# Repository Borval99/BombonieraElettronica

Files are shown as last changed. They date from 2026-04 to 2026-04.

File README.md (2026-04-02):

# Bomboniera Elettronica

## Descrizione

BombonieraElettronica è una bomboniera realizzata in occasione della tesi di Laurea Magistrale in Ingegneria Elettronica.

Il dispositivo è basato su un circuito stampato (PCB) che integra una semplice logica elettronica per la generazione di un effetto luminoso.

---

## Funzionamento

La bomboniera è dotata di un **interruttore touch**, integrato nel cappello di laurea, che consente di attivare e disattivare il circuito.

Il sistema di illuminazione è realizzato tramite un **multivibratore astabile a BJT**, che genera un segnale oscillante utilizzato per pilotare 5 Led gialli.

Il risultato è un gioco di luci intermittente.

L’alimentazione è fornita da una **batteria CR2032**, rendendo il dispositivo compatto e autonomo. La durata da spento è stimata di circa 2 Anni.

---

## Immagini

<div>
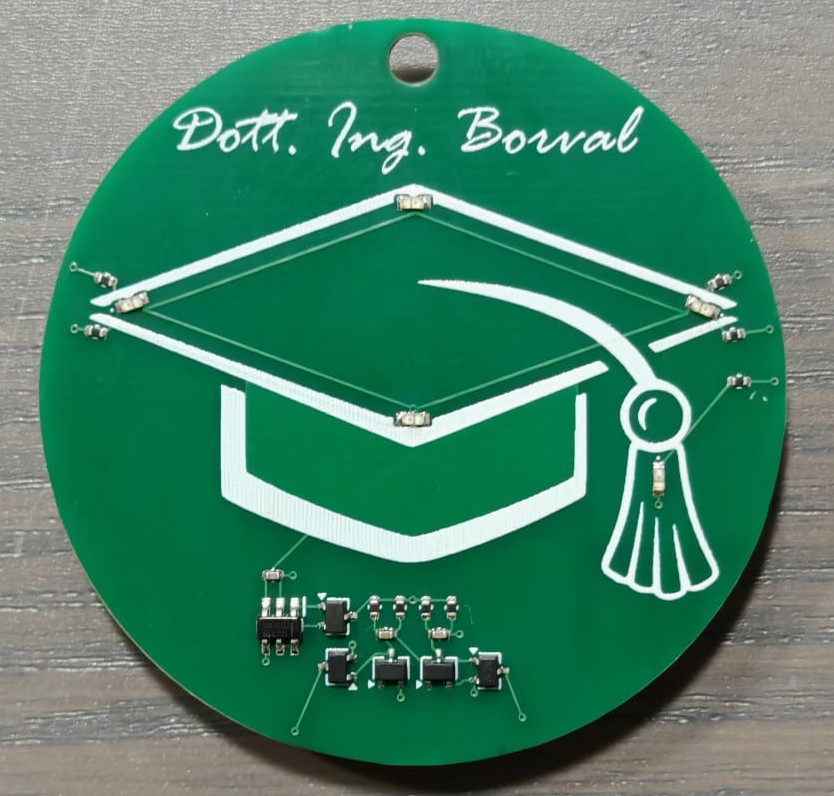
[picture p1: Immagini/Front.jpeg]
  
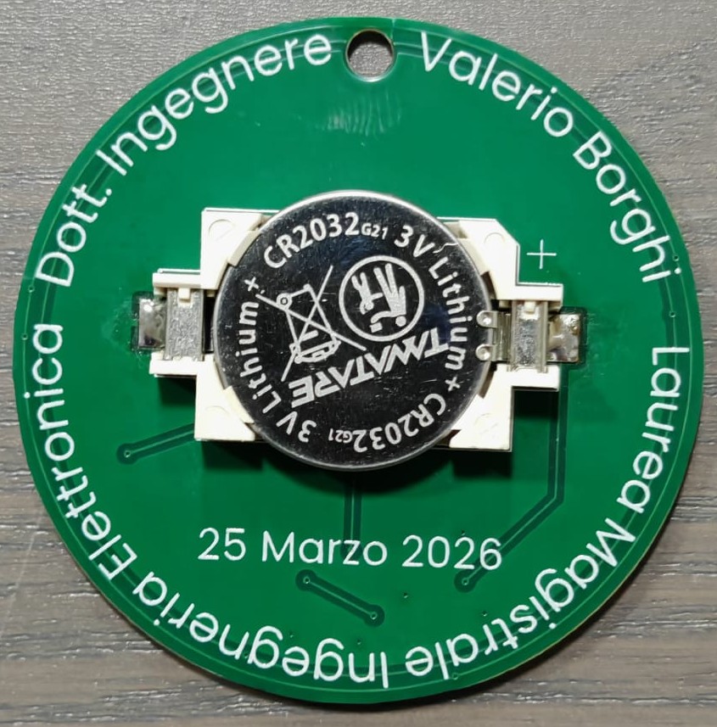
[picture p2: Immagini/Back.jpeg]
  
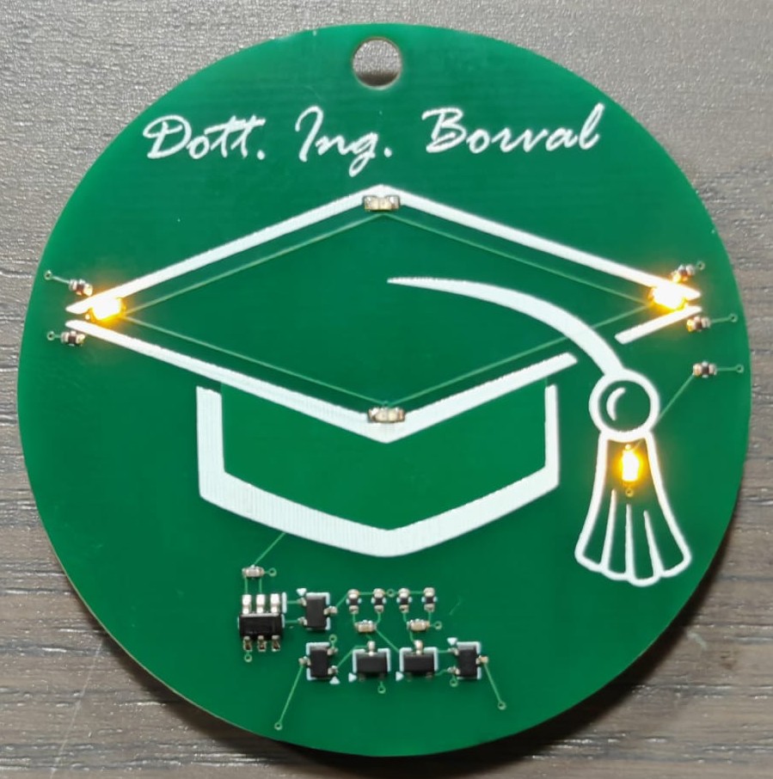
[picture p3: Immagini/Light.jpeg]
  
</div>

---

## Struttura della repository

### /Bomboniera_Tesi

Contiene il progetto elettronico completo realizzato in KiCad:

* schema elettrico
* layout del PCB

---

### /LTspice

Contiene le simulazioni dei circuiti sviluppati:

* modelli del multivibratore astabile
* analisi del comportamento del circuito

---

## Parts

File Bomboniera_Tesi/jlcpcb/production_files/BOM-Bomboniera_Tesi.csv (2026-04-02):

Comment | Designator | Footprint | LCSC | Quantity
0402WGF1003TCE | R2,R5 | R_0402_1005Metric | C25741 | 2
0402WGF1004TCE | R3,R4 | R_0402_1005Metric | C26083 | 2
BC817-40W,115 | Q3,Q4 | SOT-323_SC-70 | C53113961 | 2
CC0402JRX7R7BB104 | C1,C3 | C_0402_1005Metric | C541464 | 2
CL05C220JB5NNNC | C2 | C_0402_1005Metric | C70464 | 1
DMG1013UW-7 | Q1 | SOT-323_SC-70 | C211434 | 1
L2N7002WT1G | Q2,Q5 | SOT-323_SC-70 | C12778 | 2
LY L29K-H1K2-26-0-2-R18-Z | D1,D10,D16,D2,D6 | LED_LY L29K_MUR | C2900144 | 5
TTP223-TD | IC1 | SOT95P285X126-6N | C42422128 | 1
0402WGF3300TCE | R17 | R_0402_1005Metric |  | 1
0402WGF3300TCE | R13 | R_0402_1005Metric |  | 1
0402WGF3300TCE | R16 | R_0402_1005Metric |  | 1
0402WGF3300TCE | R1 | R_0402_1005Metric |  | 1
0402WGF3300TCE | R7 | R_0402_1005Metric |  | 1

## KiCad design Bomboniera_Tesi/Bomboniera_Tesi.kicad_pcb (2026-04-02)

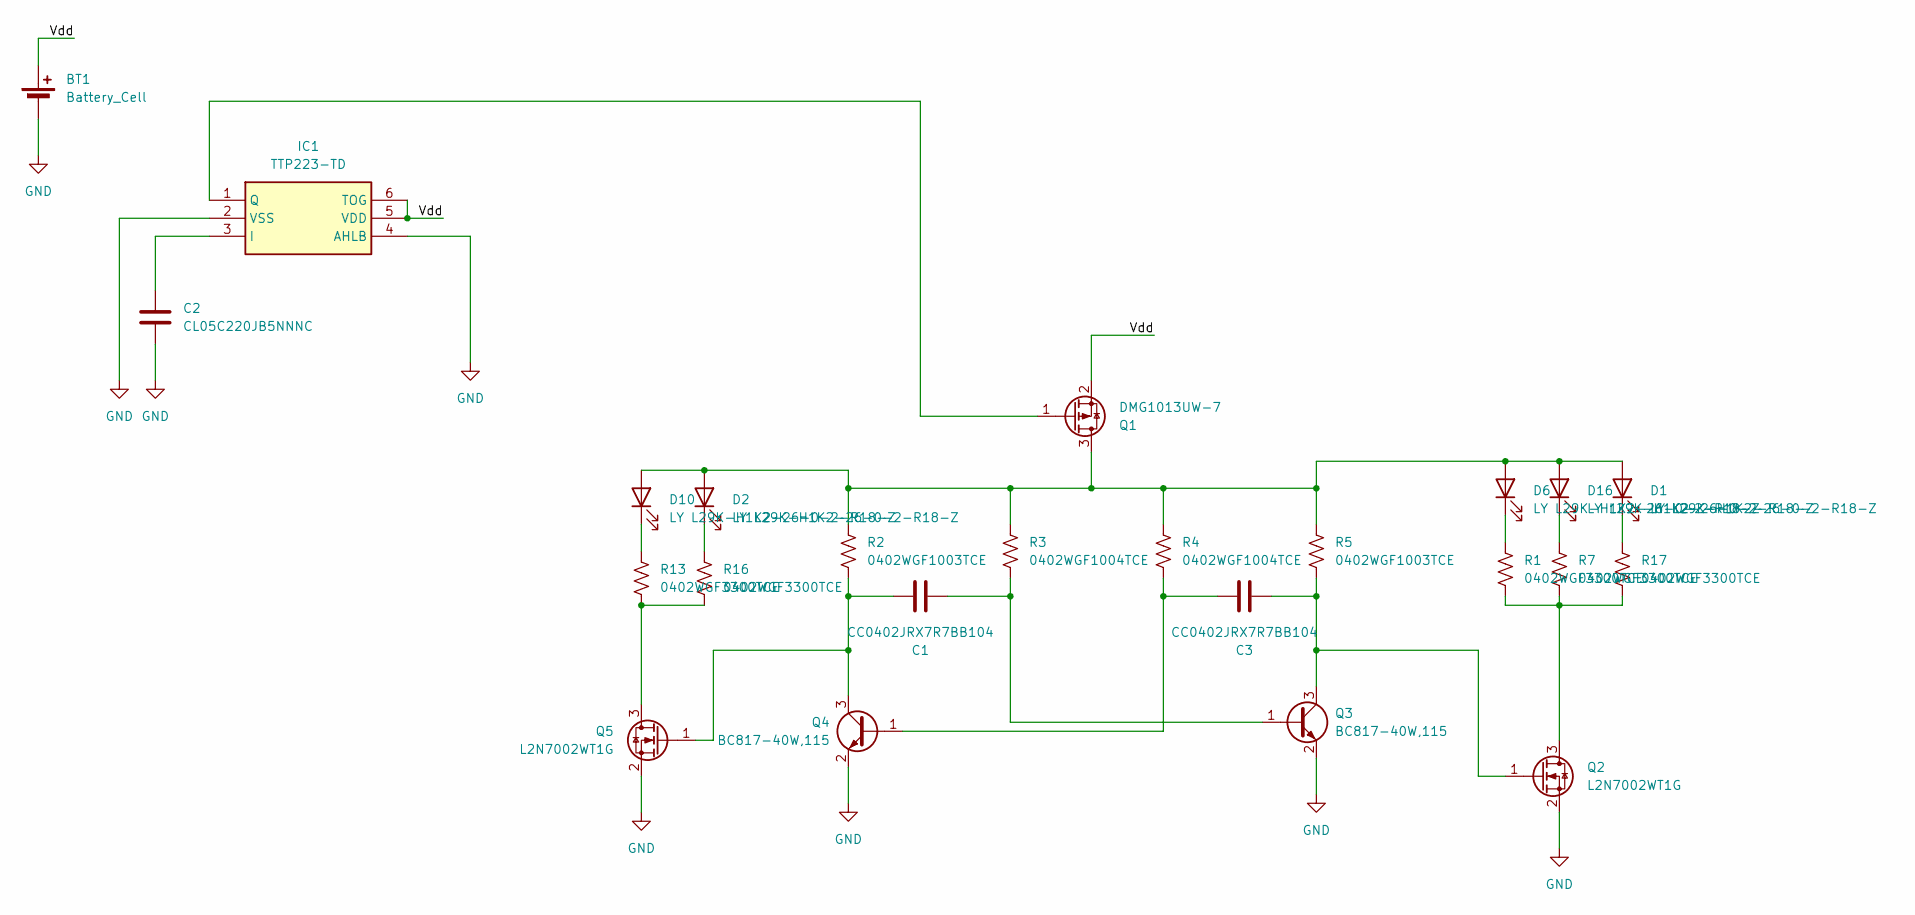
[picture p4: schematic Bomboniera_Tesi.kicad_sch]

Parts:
BT1: Battery_Cell; BatteryHolder_Keystone_1060_1x2032
C1, C3: CC0402JRX7R7BB104; C_0402_1005Metric
C2: CL05C220JB5NNNC; C_0402_1005Metric
D1, D2, D6, D10, D16: LY L29K-H1K2-26-0-2-R18-Z; LED_LY L29K_MUR
IC1: TTP223-TD; SOT95P285X126-6N
Q1: DMG1013UW-7; SOT-323_SC-70
Q2, Q5: L2N7002WT1G; SOT-323_SC-70
Q3, Q4: BC817-40W,115; SOT-323_SC-70
R1, R7, R13, R16, R17: 0402WGF3300TCE; R_0402_1005Metric
R2, R5: 0402WGF1003TCE; R_0402_1005Metric
R3, R4: 0402WGF1004TCE; R_0402_1005Metric

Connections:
/Vdd: BT1.1 (+), IC1.5 (VDD), IC1.6 (TOG), Q1.2 (S)
GND: BT1.2 (-), C2.2, IC1.2 (VSS), IC1.4 (AHLB), Q2.2 (S), Q3.2 (E), Q4.2 (E), Q5.2 (S)
unnamed: D1.2 (A), D2.2 (A), D6.2 (A), D10.2 (A), D16.2 (A), Q1.3 (D), R2.1, R3.1, R4.2, R5.1
unnamed: D1.1 (K), R17.1
unnamed: D2.1 (K), R16.1
unnamed: D6.1 (K), R1.1
unnamed: D10.1 (K), R13.1
unnamed: D16.1 (K), R7.1
unnamed: C2.1, IC1.3 (I)
unnamed: IC1.1 (Q), Q1.1 (G)
unnamed: Q2.3 (D), R1.2, R7.2, R17.2
unnamed: C3.2, Q2.1 (G), Q3.3 (C), R5.2
unnamed: C1.2, Q3.1 (B), R3.2
unnamed: C3.1, Q4.1 (B), R4.1
unnamed: C1.1, Q4.3 (C), Q5.1 (G), R2.2
unnamed: Q5.3 (D), R13.2, R16.2

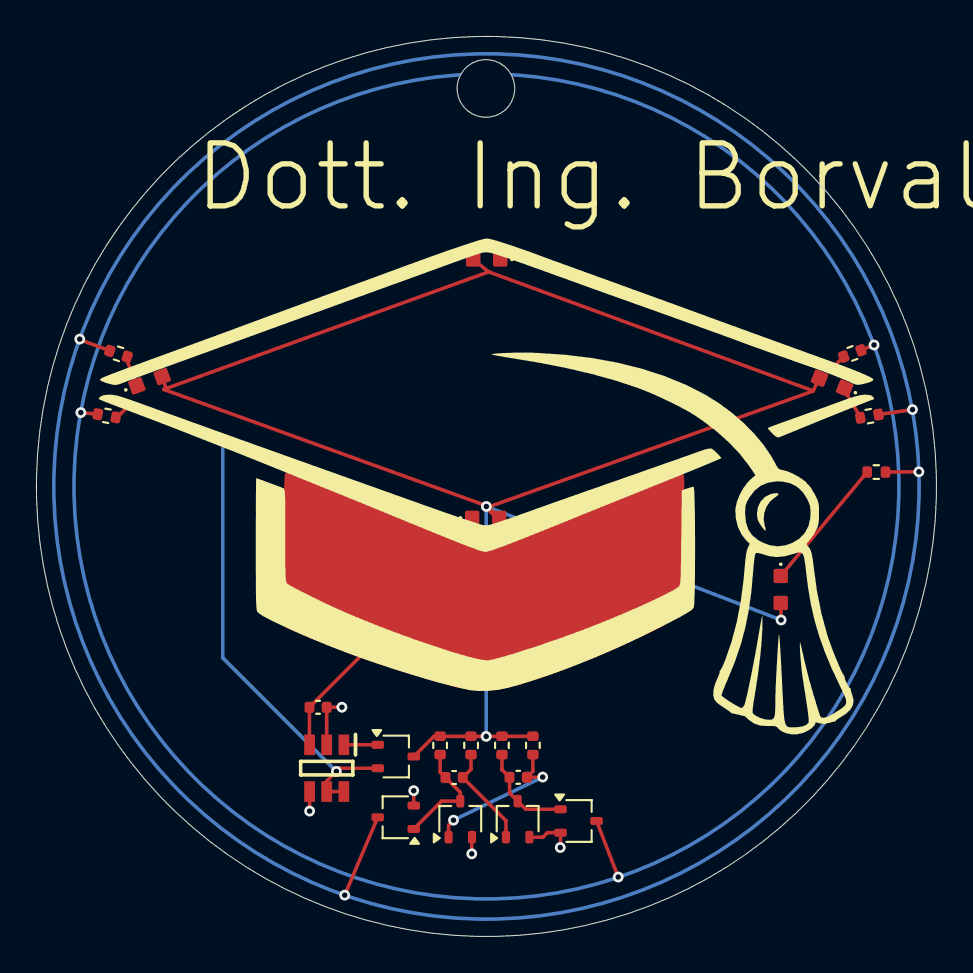
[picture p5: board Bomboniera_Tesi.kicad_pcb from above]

Board: 2 copper layers, 50.0 x 50.0 mm, 24 parts (1 on the bottom side), 16 nets.
